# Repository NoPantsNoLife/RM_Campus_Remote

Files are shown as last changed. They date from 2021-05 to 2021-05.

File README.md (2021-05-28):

# RM_Campus_Remote

## 开发说明

因为PS2遥控器太渣（摇杆只有8bit，2.4G频段用户较多，没有绑定机制，没有办法定制数据传输等），利用其外壳，开发了这个遥控器项目。

## 功能

### 基本的摇杆和按键功能

全模拟量摇杆，正常按键

### 串口通信，附加数据传输

数据包格式可自定义，可传输附加数据。本例中用数据包同时传送了PID整定参数给接收端，配合适当的上位机和接收端代码，可以实现对PID参数的实时调整

## 电路说明

因工期紧张没有单独打板，按键和摇杆板子是在原有PS2遥控器的基础上，把黑胶封装（也叫软封装，也叫牛屎封装）的主控芯片加热后铲掉，飞线后封胶固定做成的。MCU在一块最小系统板上，RF模块自己有一个模块PCB，射频部分是飞了一根同轴线连接的，

原理图中的按键等连接方式仅供参考，实际与哪个按键对应并不重要（我忘了），在程序中很容易修正

供电采用锂电池降压到3.3V，降压电路为TLV62569，模块是洞洞板紧急搭的

锂电池充电模块TP4056

引出接口加了ESD二极管避免静电击穿

## 程序简述

关于SX1231驱动请看https://github.com/NoPantsNoLife/SX1231_STM32_Driver

整个项目是STM32CubeMX生成的，全部使用LL库

模拟量摇杆的电压值用ADC采样，循环DMA传输到内存里，需要发送的时候直接取

USART接收到的数据也用DMA放到内存里，目前是24个字节，即留出一共4组PID参数的位置，每组PID参数占了6个字节

上位机软件的工作就是不断地向下位机发送这24个字节

按键的状态读取后，用位操作拼成两个字节

所有数据准备好后通过SX1231模块发送出去，只要遥控器有电就不停发送

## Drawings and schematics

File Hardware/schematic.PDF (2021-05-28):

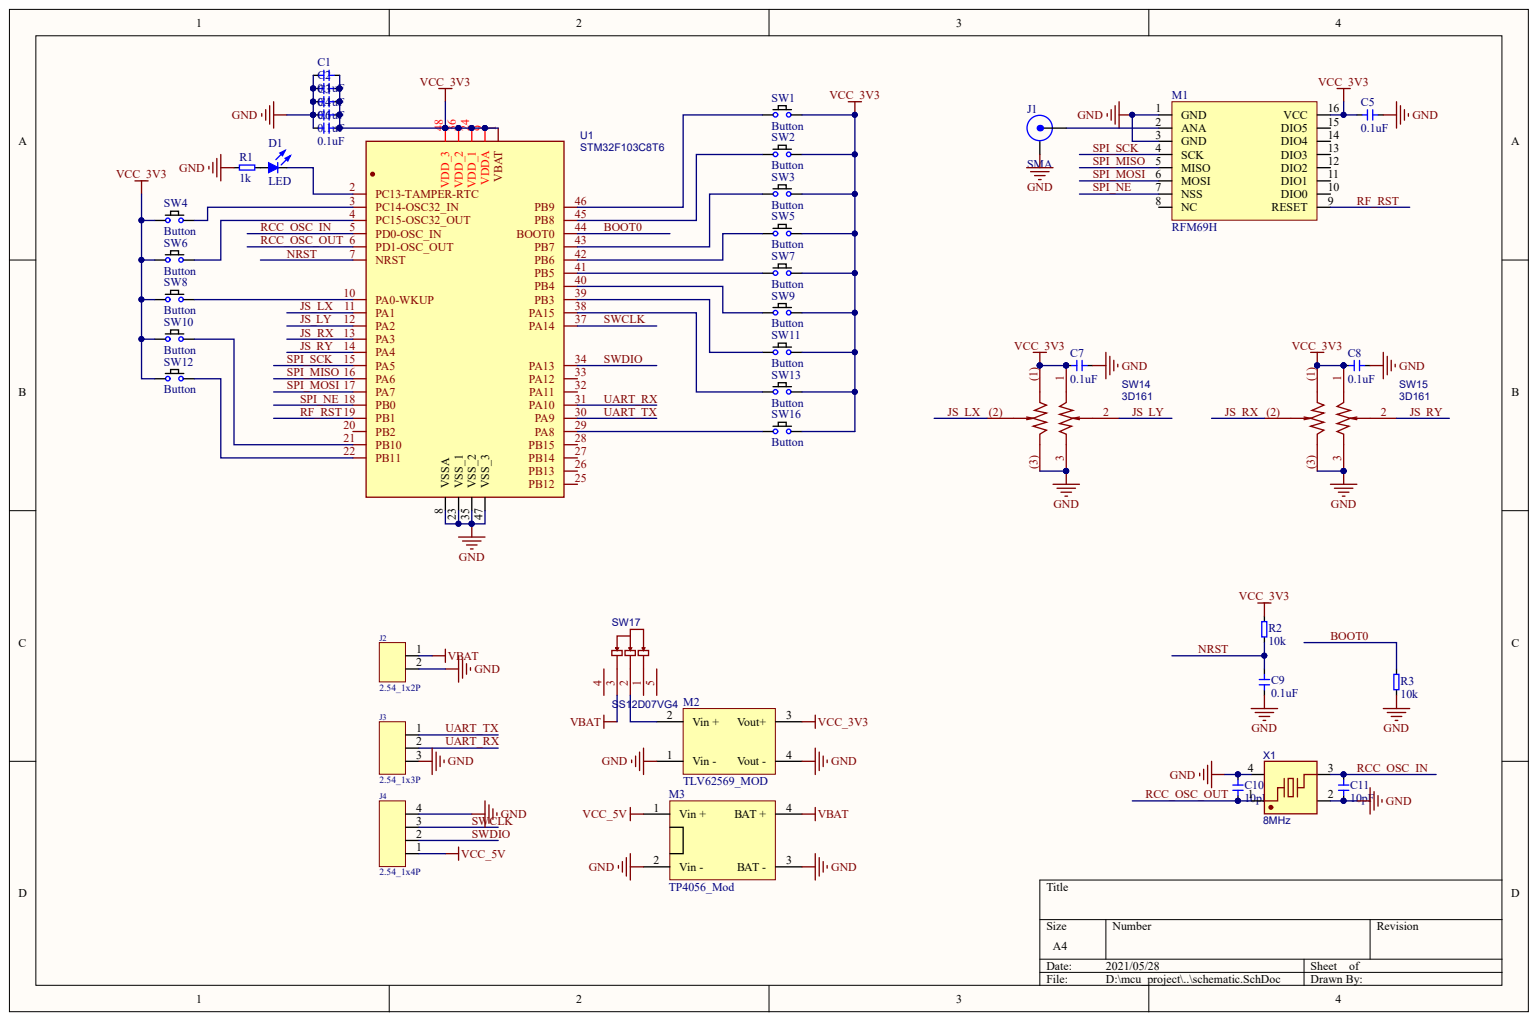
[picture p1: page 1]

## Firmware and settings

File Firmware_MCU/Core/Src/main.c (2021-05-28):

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
/* Includes ------------------------------------------------------------------*/
#include "main.h"
#include "adc.h"
#include "dma.h"
#include "spi.h"
#include "usart.h"
#include "gpio.h"

/* USER CODE BEGIN Includes */
#include "stdio.h"
#include "SX1231_APP.h"

/* USER CODE END Includes */


/* USER CODE BEGIN PV */
uint16_t ADC_Val[4];

/* USER CODE END PV */

void SystemClock_Config(void);
/**
  * @brief  The application entry point.
  * @retval int
  */
int main(void)
{
  /* USER CODE BEGIN 1 */
	int i, a, b, c, d, uart_rx_invalid;
	uint8_t bfr[SX1231_PayloadLength];
	__IO uint8_t UART_Buf[24];
  /* USER CODE END 1 */

  /* MCU Configuration--------------------------------------------------------*/

  /* Reset of all peripherals, Initializes the Flash interface and the Systick. */

  LL_APB2_GRP1_EnableClock(LL_APB2_GRP1_PERIPH_AFIO);
  LL_APB1_GRP1_EnableClock(LL_APB1_GRP1_PERIPH_PWR);

  NVIC_SetPriorityGrouping(NVIC_PRIORITYGROUP_4);

  /* System interrupt init*/

  /** NOJTAG: JTAG-DP Disabled and SW-DP Enabled
  */
  LL_GPIO_AF_Remap_SWJ_NOJTAG();

  /* Configure the system clock */
  SystemClock_Config();

  /* Initialize all configured peripherals */
  MX_GPIO_Init();
  MX_DMA_Init();
  MX_SPI1_Init();
  MX_ADC1_Init();
  MX_USART1_UART_Init();
  /* USER CODE BEGIN 2 */
	LL_SPI_Enable(SPI1);
	
	LL_DMA_SetDataLength(DMA1, LL_DMA_CHANNEL_1, 4);
	LL_DMA_SetPeriphAddress(DMA1, LL_DMA_CHANNEL_1, LL_ADC_DMA_GetRegAddr(ADC1, LL_ADC_DMA_REG_REGULAR_DATA));
	LL_DMA_SetMemoryAddress(DMA1, LL_DMA_CHANNEL_1, (uint32_t)ADC_Val);
	LL_DMA_EnableChannel(DMA1, LL_DMA_CHANNEL_1);
	
	LL_ADC_Enable(ADC1);
	LL_ADC_StartCalibration(ADC1);
	while(LL_ADC_IsCalibrationOnGoing(ADC1));

	LL_ADC_REG_SetDMATransfer(ADC1,LL_ADC_REG_DMA_TRANSFER_UNLIMITED);
	
	
	
	
	LL_DMA_SetDataLength(DMA1, LL_DMA_CHANNEL_5, 24);
	LL_DMA_SetPeriphAddress(DMA1, LL_DMA_CHANNEL_5, LL_USART_DMA_GetRegAddr(USART1));
	LL_DMA_SetMemoryAddress(DMA1, LL_DMA_CHANNEL_5, (uint32_t)UART_Buf);
	LL_DMA_EnableChannel(DMA1, LL_DMA_CHANNEL_5);
	LL_USART_EnableDMAReq_RX(USART1);
	
	


	
	//printf("%d", sizeof(float));
	LL_GPIO_ResetOutputPin(GPIOC, LL_GPIO_PIN_13);
	
	SX1231_Init_Primary();
  while (!SX1231_IsActiveFlag_ModeReady(&SX1231_Primary))
  {
    //printf("wait\r\n");
  }
	
	

  
  while(1)
	{
		if(LL_DMA_IsActiveFlag_TC5(DMA1))
		{
			uart_rx_invalid = 0;
			LL_DMA_DisableChannel(DMA1, LL_DMA_CHANNEL_5);
			LL_DMA_ClearFlag_TC5(DMA1);
			LL_USART_ClearFlag_IDLE(USART1);
			LL_DMA_SetDataLength(DMA1, LL_DMA_CHANNEL_5, 24);
			LL_DMA_EnableChannel(DMA1, LL_DMA_CHANNEL_5);
			
			UART_Buf[15] = 0;
		}
		else
		{
			uart_rx_invalid++;
			if(uart_rx_invalid > 10)
			{
				uart_rx_invalid = 0;
				LL_DMA_DisableChannel(DMA1, LL_DMA_CHANNEL_5);
				LL_USART_DisableDMAReq_RX(USART1);
				LL_USART_EnableDMAReq_RX(USART1);
				LL_DMA_SetDataLength(DMA1, LL_DMA_CHANNEL_5, 24);
				LL_DMA_EnableChannel(DMA1, LL_DMA_CHANNEL_5);
				UART_Buf[0] = 9;
				UART_Buf[1] = 3;
				UART_Buf[2] = 2;
				UART_Buf[3] = 7;
				UART_Buf[4] = 10;
				UART_Buf[5] = 4;
			}
		}
    
		a = (LL_GPIO_IsInputPinSet(GPIOA, LL_GPIO_PIN_8) ? 0x01 : 0 ) +
				(LL_GPIO_IsInputPinSet(GPIOA, LL_GPIO_PIN_15) ? 0x02 : 0 ) +
				(LL_GPIO_IsInputPinSet(GPIOB, LL_GPIO_PIN_3) ? 0x04 : 0 ) +
				(LL_GPIO_IsInputPinSet(GPIOB, LL_GPIO_PIN_4) ? 0x08 : 0 ) +
				(LL_GPIO_IsInputPinSet(GPIOB, LL_GPIO_PIN_5) ? 0x10 : 0 ) +
				(LL_GPIO_IsInputPinSet(GPIOB, LL_GPIO_PIN_6) ? 0x20 : 0 ) +
				(LL_GPIO_IsInputPinSet(GPIOB, LL_GPIO_PIN_7) ? 0x40 : 0 ) +
				(LL_GPIO_IsInputPinSet(GPIOB, LL_GPIO_PIN_8) ? 0x80 : 0 ) ;
		
		b = (LL_GPIO_IsInputPinSet(GPIOB, LL_GPIO_PIN_9) ? 0x01 : 0 ) +
				(LL_GPIO_IsInputPinSet(GPIOB, LL_GPIO_PIN_10) ? 0x02 : 0 ) +
				(LL_GPIO_IsInputPinSet(GPIOB, LL_GPIO_PIN_11) ? 0x04 : 0 ) +
				(LL_GPIO_IsInputPinSet(GPIOC, LL_GPIO_PIN_14) ? 0x08 : 0 ) +
				(LL_GPIO_IsInputPinSet(GPIOC, LL_GPIO_PIN_15) ? 0x10 : 0 ) ;
		
		
		//printf("%02x %02x %03x %03x %03x %03x\r\n", a, b, ADC_Val[0], ADC_Val[1], ADC_Val[2], ADC_Val[3]);
		bfr[0] = 0x23;
		bfr[1] = 0x33;
		bfr[2] = a;
		bfr[3] = b;
		bfr[4] = ADC_Val[0] >> 8;
		bfr[5] = ADC_Val[0] & 0xff;
		bfr[6] = ADC_Val[1] >> 8;
		bfr[7] = ADC_Val[1] & 0xff;
		bfr[8] = ADC_Val[2] >> 8;
		bfr[9] = ADC_Val[2] & 0xff;
		bfr[10] = ADC_Val[3] >> 8;
		bfr[11] = ADC_Val[3] & 0xff;
		
		bfr[12] = UART_Buf[0];
		bfr[13] = UART_Buf[1];
		bfr[14] = UART_Buf[2];
		bfr[15] = UART_Buf[3];
		bfr[16] = UART_Buf[4];
		bfr[17] = UART_Buf[5];
		
		bfr[18] = UART_Buf[6];
		bfr[19] = UART_Buf[7];
		bfr[20] = UART_Buf[8];
		bfr[21] = UART_Buf[9];
		bfr[22] = UART_Buf[10];
		bfr[23] = UART_Buf[11];
		
		bfr[24] = UART_Buf[12];
		bfr[25] = UART_Buf[13];
		bfr[26] = UART_Buf[14];
		bfr[27] = UART_Buf[15];
		bfr[28] = UART_Buf[16];
		bfr[29] = UART_Buf[17];
		
		bfr[30] = UART_Buf[18];
		bfr[31] = UART_Buf[19];
		bfr[32] = UART_Buf[20];
		bfr[33] = UART_Buf[21];
		bfr[34] = UART_Buf[22];
		bfr[35] = UART_Buf[23];
		
		printf("kP = %f, kI = %f, kD = %f\r\n", (float)bfr[12] + (float)bfr[13] / 10, (float)bfr[14] + (float)bfr[15] / 10, (float)bfr[16] + (float)bfr[17] / 10);
    
		SX1231_Primary_TransmitPacket(bfr);
  }
	
  /* USER CODE END 2 */

  /* Infinite loop */
  /* USER CODE BEGIN WHILE */
  while (1)
  {
		
    /* USER CODE END WHILE */

    /* USER CODE BEGIN 3 */
  }
  /* USER CODE END 3 */
}

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
/* USER CODE BEGIN 4 */
int fputc(int ch, FILE* f)
{
	LL_USART_TransmitData8(USART1, (unsigned char)ch);
	while(!LL_USART_IsActiveFlag_TXE(USART1));
	return ch;
}

/* USER CODE END 4 */
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


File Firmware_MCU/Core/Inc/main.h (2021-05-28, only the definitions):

#define SPI_NE_Pin LL_GPIO_PIN_0
#define SPI_NE_GPIO_Port GPIOB
#define RF_RST_Pin LL_GPIO_PIN_1
#define RF_RST_GPIO_Port GPIOB
#define NVIC_PRIORITYGROUP_0         ((uint32_t)0x00000007) /*!< 0 bit  for pre-emption priority,
#define NVIC_PRIORITYGROUP_1         ((uint32_t)0x00000006) /*!< 1 bit  for pre-emption priority,
#define NVIC_PRIORITYGROUP_2         ((uint32_t)0x00000005) /*!< 2 bits for pre-emption priority,
#define NVIC_PRIORITYGROUP_3         ((uint32_t)0x00000004) /*!< 3 bits for pre-emption priority,
#define NVIC_PRIORITYGROUP_4         ((uint32_t)0x00000003) /*!< 4 bits for pre-emption priority,

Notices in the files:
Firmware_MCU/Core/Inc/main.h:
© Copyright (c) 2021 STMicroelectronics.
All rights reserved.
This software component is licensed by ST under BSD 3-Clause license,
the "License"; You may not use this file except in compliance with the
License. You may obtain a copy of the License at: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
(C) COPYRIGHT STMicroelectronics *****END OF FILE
